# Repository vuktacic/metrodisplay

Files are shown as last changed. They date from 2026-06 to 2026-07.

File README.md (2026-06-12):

# MD
## Description
MD (metrodisplay) is a big LED matrix assembly with game controls to play pong and tetris (in progress). It's built with four outdoor (very bright) P5 64x32 panels, a custom pcb with an esp32, a cnc'd wooden frame, and power distribution from mains AC. The total cost of the project is under $90 USD.

I was originally making a small project with a single LED panel to display subway times for the Vancouver Skytrain (hence the name), but I realized that while that was great for a static bedroom display, something much more exciting and interactive like this would be much more fun to showcase at Opensauce!

## TODO List
- [x] Pong game
- [ ] Tetris game (in progress)
- [ ] Concept art
- [ ] CNC designs
- [ ] CNC toolpathing
- [ ] CNCing
- [ ] Frame building
- [ ] Electronics Setup
- [ ] Final tests
- [ ] Dismantling
- [ ] Present at Opensauce!

## Structure
- [./cad](./cad): STEP & F3D
- [./pcb](./pcb): PCB Files.
- [./mdcore](./mdcore): Firmware
- [./bom.csv](./bom.csv): Bill of Materials
- [./JOURNAL.md](./JOURNAL.md): Journal

View the PCB on KiCanvas:  


## CAD
### Frame
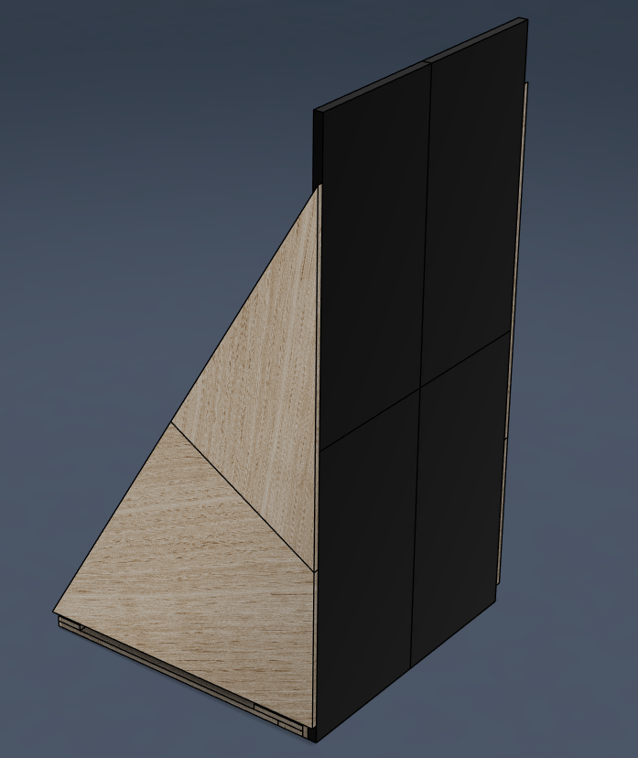
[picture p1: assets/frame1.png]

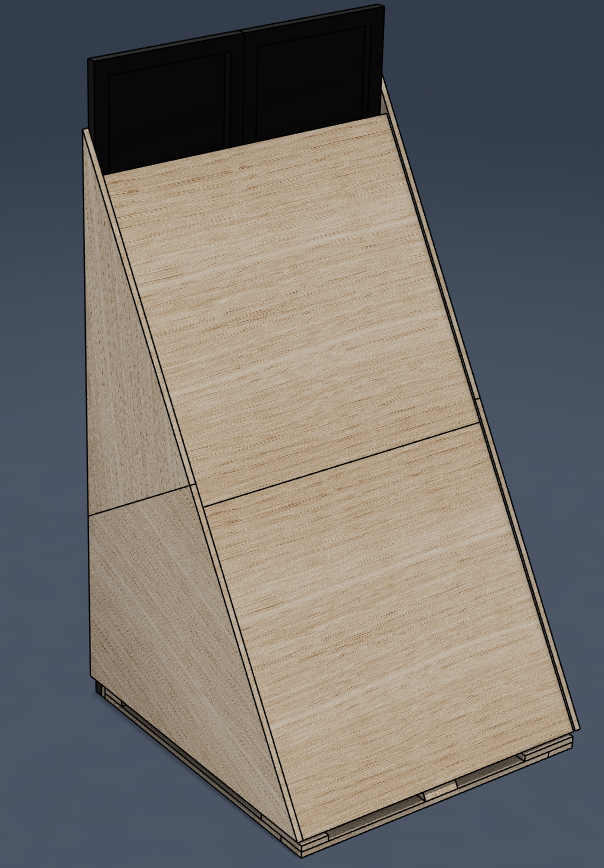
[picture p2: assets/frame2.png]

Frame designed to be disassembled to fit in standard carry-on luggage.

### Controllers
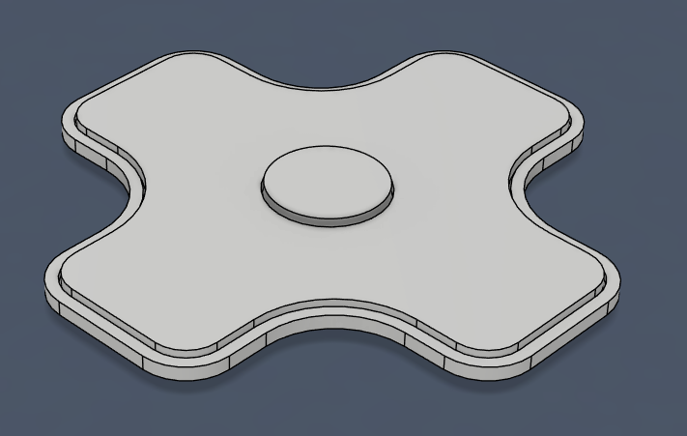
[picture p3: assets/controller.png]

Controllers are 22cm wide

## Electronics
### PCB
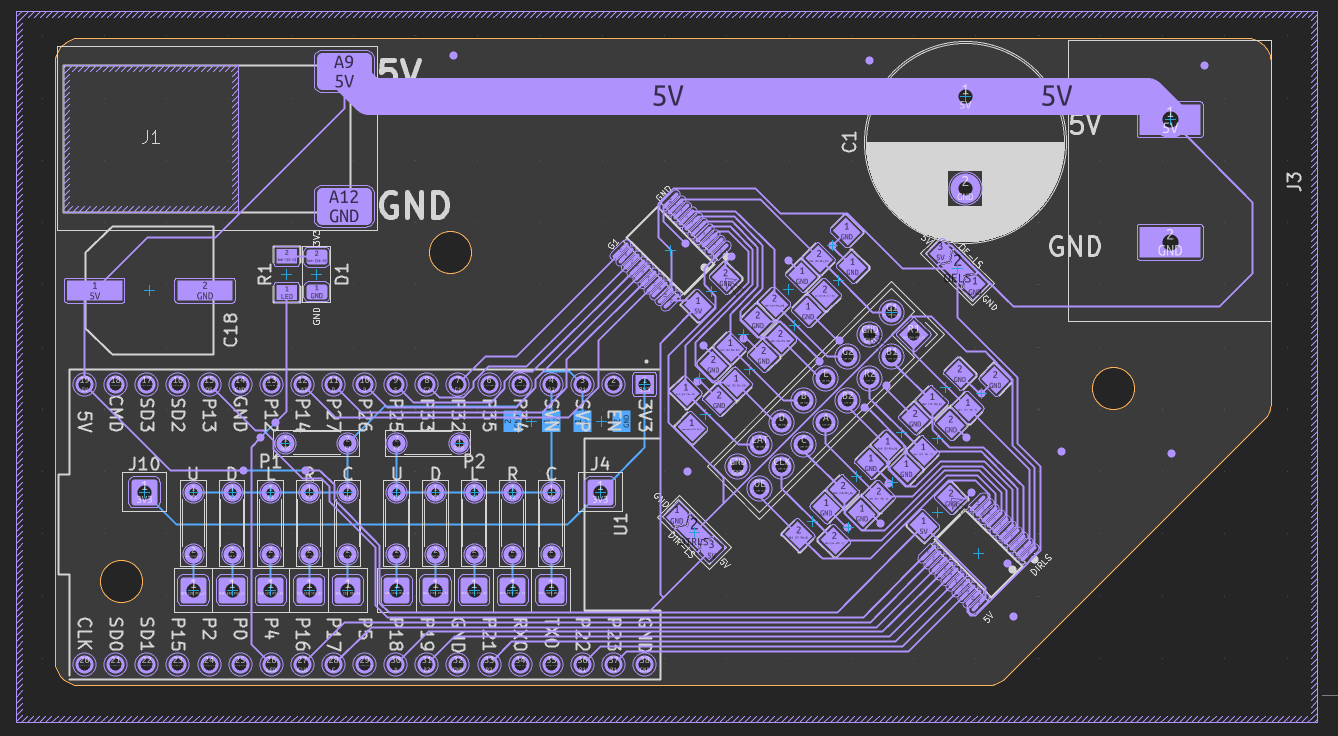
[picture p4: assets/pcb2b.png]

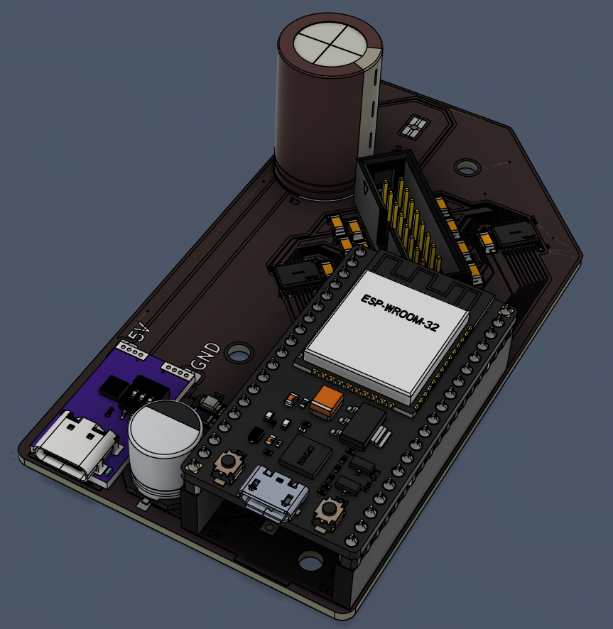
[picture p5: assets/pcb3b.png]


### Schematic
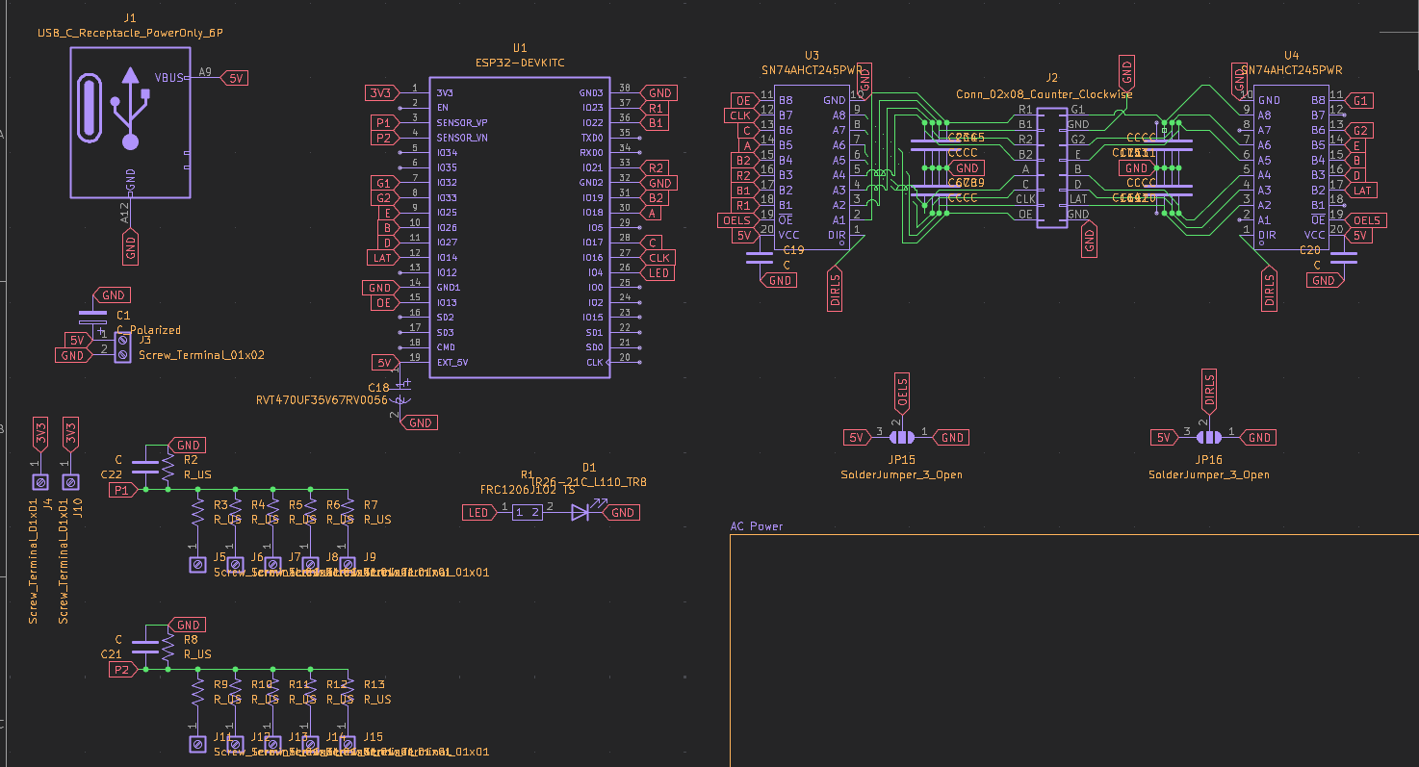
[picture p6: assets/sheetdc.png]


### Power Distribution
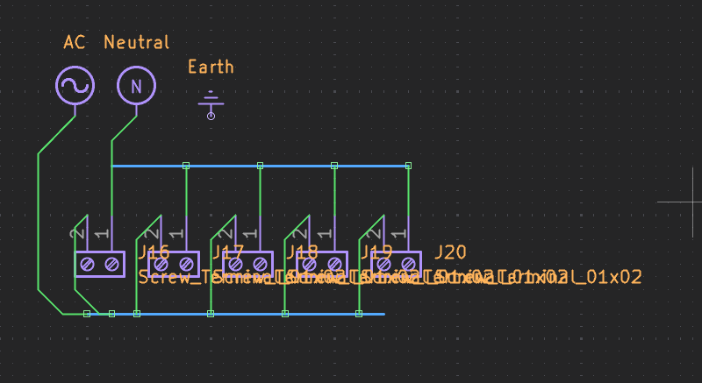
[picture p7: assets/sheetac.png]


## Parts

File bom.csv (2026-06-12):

Item | Qty | Price (CAD) | Link | Note
Outdoor P5 64x32 LED Panel (320mmx160mm) | 4 | $108.76 | https://www.aliexpress.com/item/1005003654005236.html | 1/8 scan
2x4 wood | 1 | $0.00 | n/a
1/8 in plywood 3'x6' | 1 | $0.00 | n/a
2.54 MM Pitch DC3 2x8 16P Socket Box Header | 10 | $2.25 | https://www.aliexpress.com/item/1005004252439201.html | PCB connector
SN74AHCT245PWR TSSOP20 Level Shifter 3V3 to 5V | 10 | $4.19 | https://www.aliexpress.com/item/1005006837883056.html | Translator for LED Panel
ESP32 Devkit | 1 | $0.00 | n/a
1206 Blue LED | 1 | $0.80 | https://leeselectronic.com/en/product/55614-led-1206-smd-blue.html
100nF 1206 Ceramic Capacitor | 19 | $0.00 | n/a
470uF 25V Electrolytic Capacitor | 1 | $0.00 | n/a
1kΩ 1206 Resistor | 1 | $0.00 | n/a
10kΩ THT Resistor | 4 | $0.00 | n/a | Pulldown Resistor & Resistor Ladder
1kΩ THT Resistor | 2 | $0.00 | n/a | Resistor Ladder
2.2kΩ THT Resistor | 2 | $0.00 | n/a | Resistor Ladder
4.7kΩ THT Resistor | 2 | $0.00 | n/a | Resistor Ladder
22kΩ THT Resistor | 2 | $0.00 | n/a | Resistor Ladder
6mmx6mm Push Button | 10 | $0.00 | n/a
5-way WAGO Splitter | 2 | $0.00 | n/a | Power Distribution
AC Power Cable | 1 | $6.99 | https://www.aliexpress.com/item/1005001405584434.html | Power
JLCPCB | 5 | $4.89 | https://jlcpcb.com/
**TOTAL (CAD)** |  | $127.78
**TOTAL (USD)** |  | $91.45

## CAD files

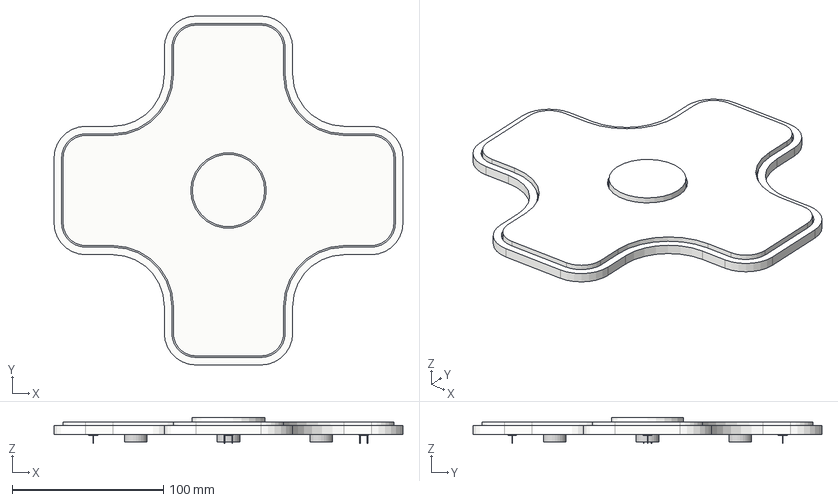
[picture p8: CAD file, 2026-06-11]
cad/Controller.step
231.0 x 231.0 x 17.5 mm
part_object_id_9 x 5
part_object_id_10 x 5
part_object_id_11 x 5
part_object_id_12 x 5
part_object_id_13 x 5
part_object_id_14 x 5
part_object_id_15 x 5
part_object_id_16 x 5

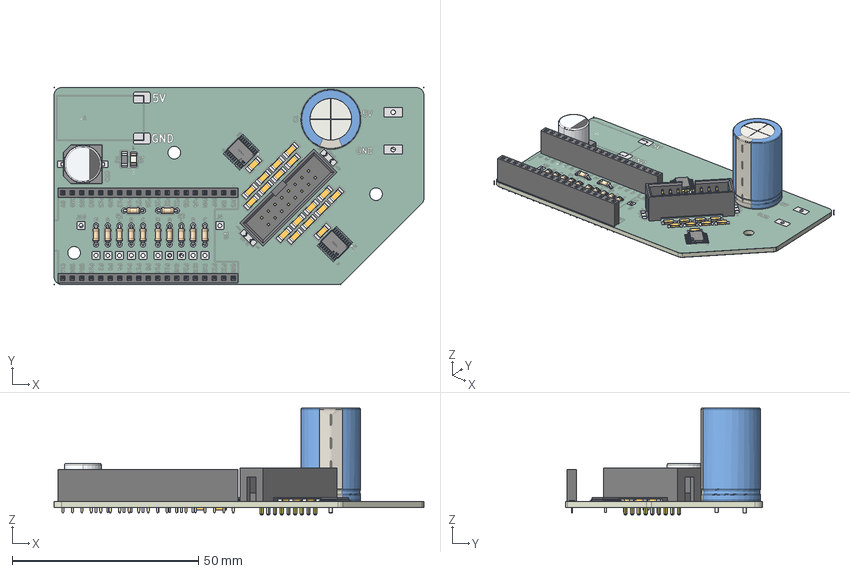
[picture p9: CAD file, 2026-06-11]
pcb/pcb.step
99.3 x 52.9 x 28.6 mm
C1206_L3.2-W1.6-H1.3 x 20
R_Axial_DIN0204_L3.6mm_D1.6mm_P5.08mm_Horizontal x 12
DS1013-16S (IDC-16MS CONNFLY)
LED_1206_3216Metric
TSSOP-20_L6.5-W4.4-H1.0-LS6.4-P0.65 x 2
R1206_L3.2-W1.6-H0.6
PinSocket_1x19_P2.54mm_Vertical x 2
CP_Radial_D16.0mm_P7.50mm
CAP-SMD_BD10.0-L10.3-W10.3-H10.2
metrodisplay_copper
metrodisplay_pad
metrodisplay_via
metrodisplay_silkscreen x 2
metrodisplay_soldermask x 2
metrodisplay_PCB_1
metrodisplay_PCB_2
metrodisplay_PCB_3
metrodisplay_PCB_4
metrodisplay_PCB_5
metrodisplay_PCB_6

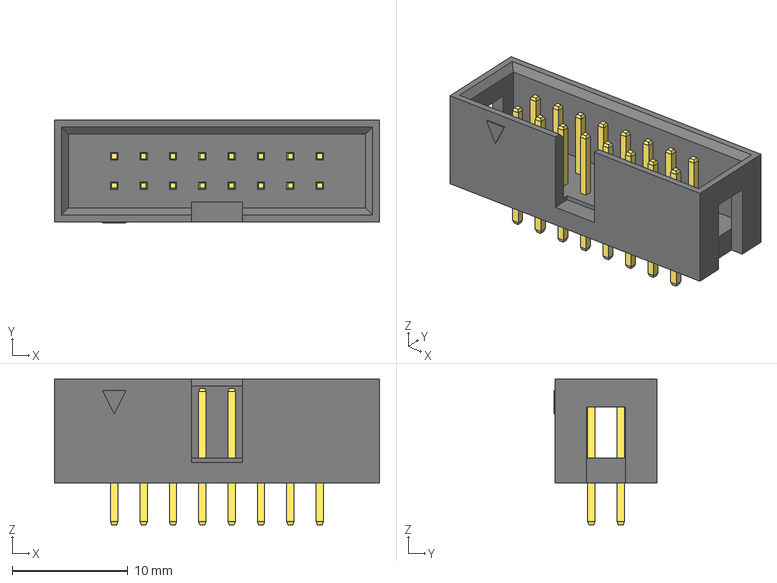
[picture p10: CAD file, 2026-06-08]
cad/DS1013-16S (IDC-16MS CONNFLY).stp
28.1 x 8.90 x 12.6 mm

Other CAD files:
cad/Controller.f3z

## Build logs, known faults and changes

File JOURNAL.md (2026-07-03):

# MD Journal

## June 5th, 2026

Started working on my project. This has been on my mind for quite a while: an led matrix board that displays subway timetables.

I've seen quite a few projects of this online, but they all use low resolution led matrices, or use them from overpriced suppliers (sorry adafruit).

First thing I did was find the led matrix I wanted to use. I found a 128x64 led matrix on aliexpress for ~$35CAD. Sounds expensive, but a 64x32 from adafruit is twice as expensive for 1/4th the pixels, so I think it's a pretty sweet deal.

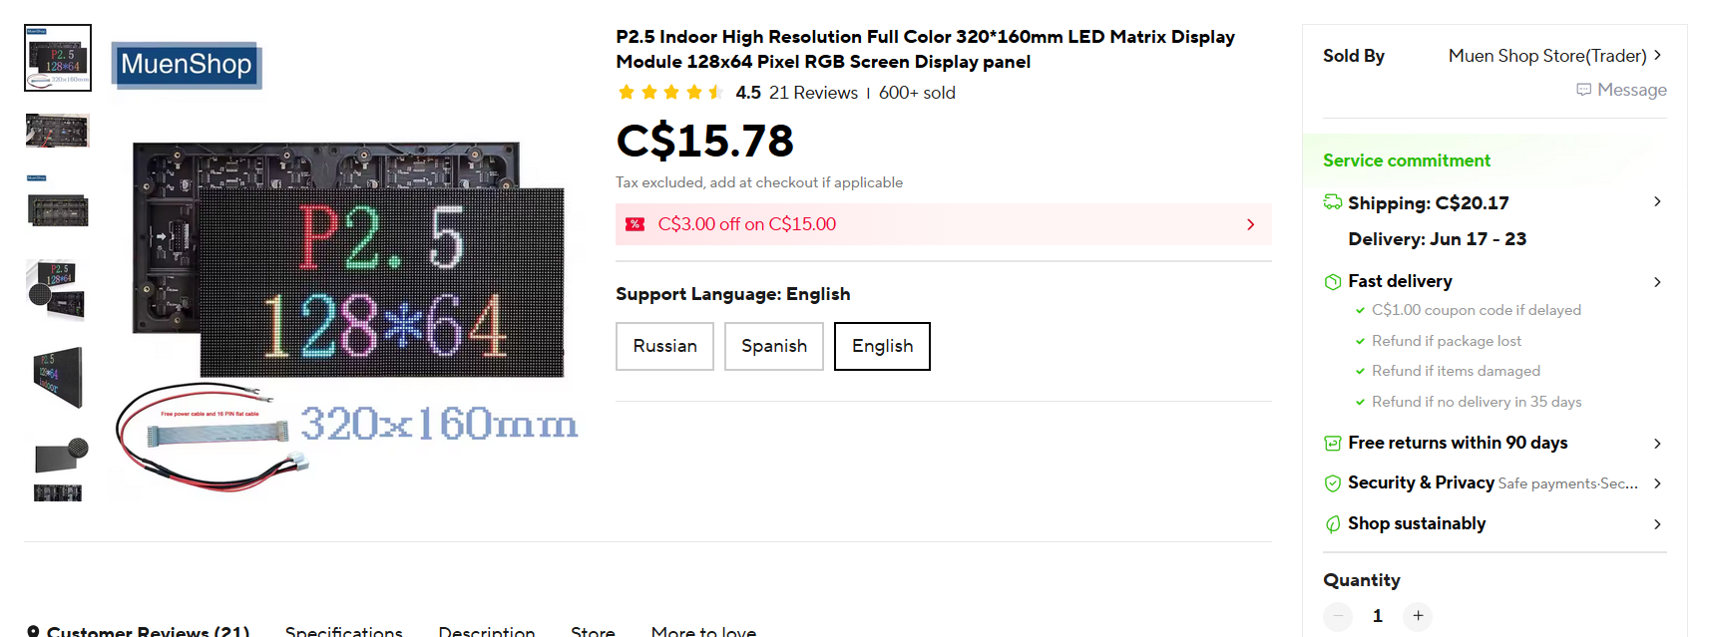
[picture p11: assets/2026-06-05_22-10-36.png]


I then built a schematic centered around my esp32 devboard to run this display.

The matrix uses a 2x8 IDC pinout, presumed to be 2.54mm pitch. I added a button for control, an led for status, level shifters for the data lines (to upgrade the 3.3V logic from the esp32 to 5V for the display), and lots and lots of decoupling capacitors (including a BEEFY 2200uF cap for the display).

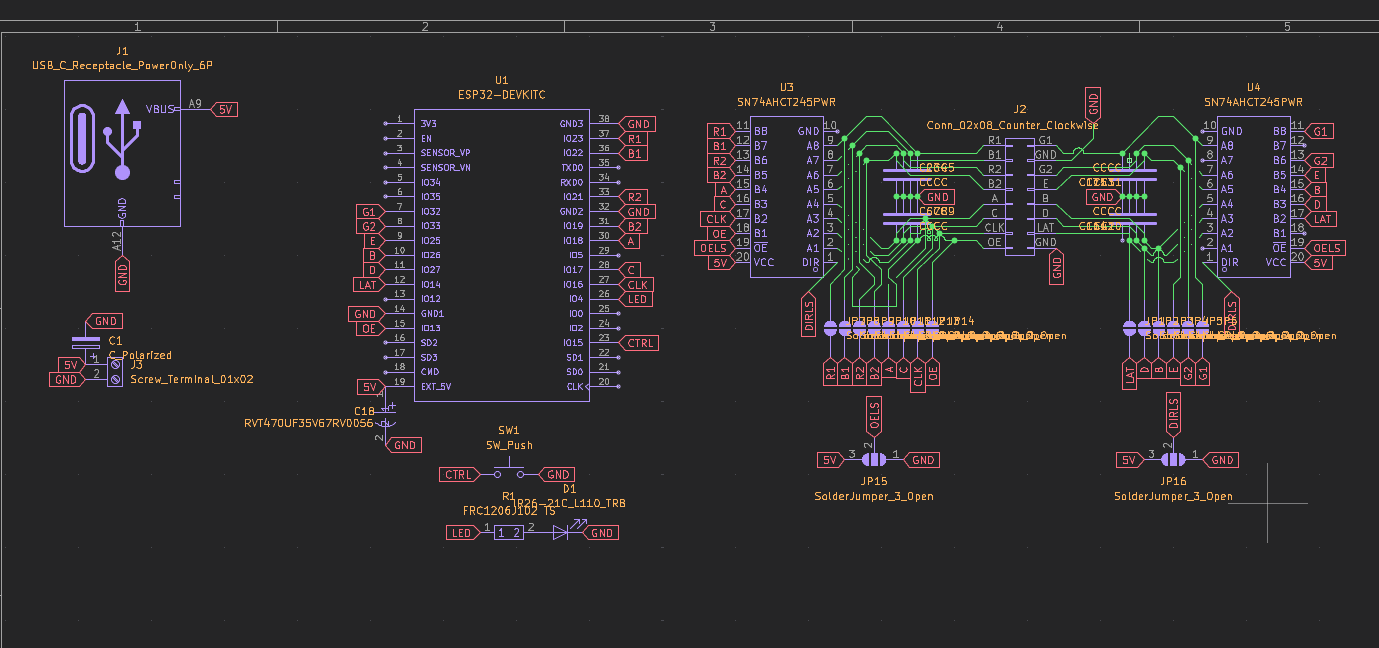
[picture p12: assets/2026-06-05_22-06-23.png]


As you can see the level shifting schematic is a bit of a mess because of how many lines there are. I added solder jumpers just in case I'm unable to use the level shifters, and the display still works with 3.3V logic.

About that capacitor: I found several boxes full of these in my school's shops (I'm talking maybe 100+ of these things). I don't think they've ever been used for something other than students blowing them up for fun, so I'm pretty excited to have a practical usecase for one of them.

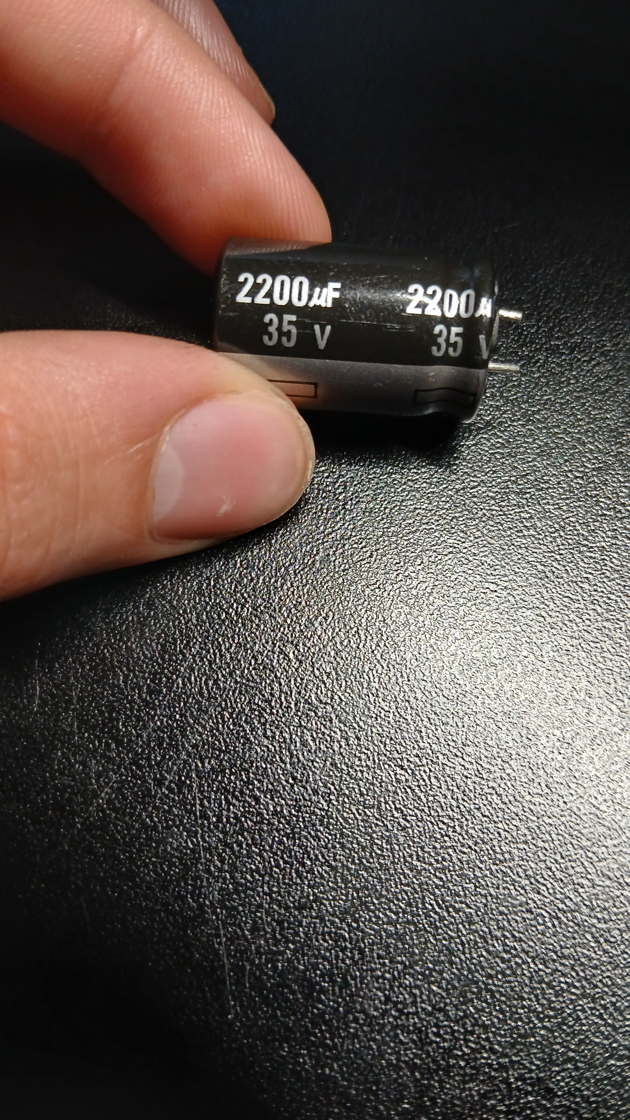
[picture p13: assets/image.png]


I then assigned footprints and brought everything into the editor. (No errors!). I set a 100mmx100mm box (JLC price limit), and started arranging the components. I wasn't worried about precise alignments, as the goal was just to see if everything could fit nicely.

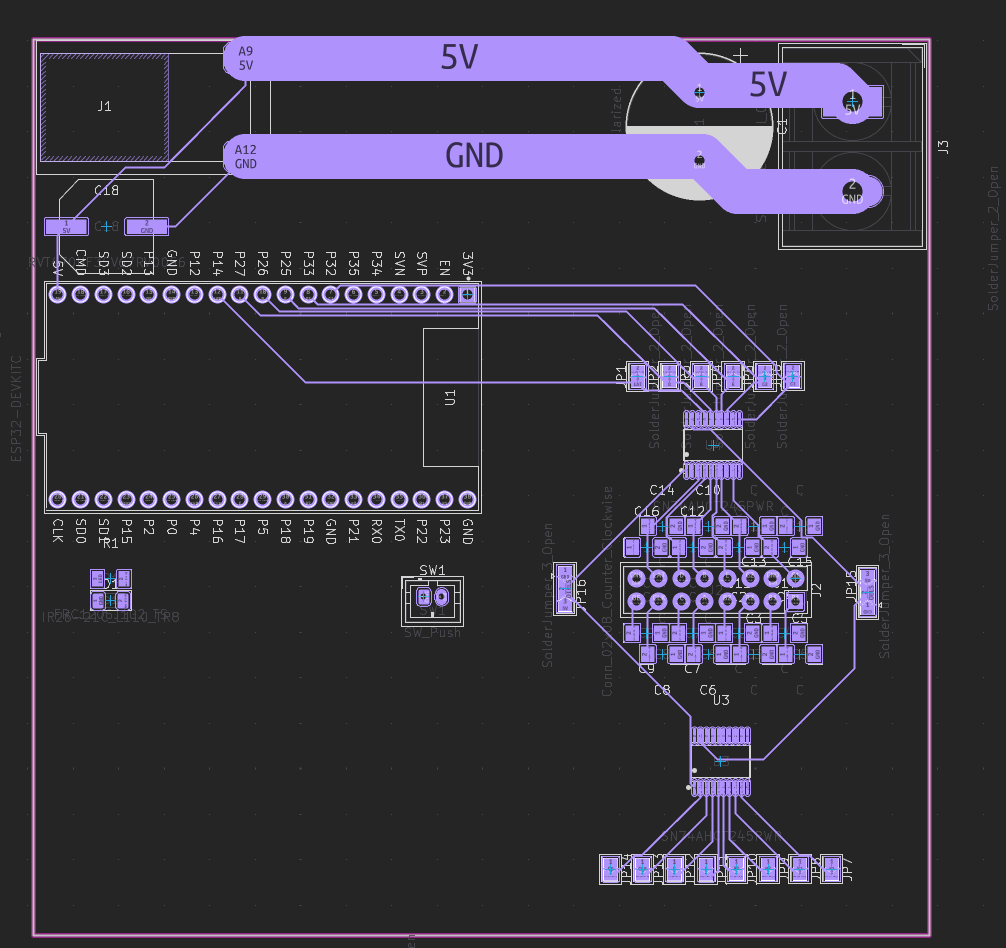
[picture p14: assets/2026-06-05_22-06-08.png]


Well, there is quite a lot of room there. I will still need to add vias for some of the solder jumpers though.

I also put down 5mm wide traces for the led 5v/gnd rails. Overkill? Yeah. But I'm not taking any chances when this matrix flicks on and pulls a billion amps.

In the following days I'll put down the actual aligned placements of all of these components, and then start routing. After that, I'll design the case for the pcb and display, and then write the firmware for it (I'm considering a webserver).

Time today: 6.0 hours  
**Time total: 6.0 hours**  
_(I'm probably going to include lapse links from now on.)_

## June 6th, 2026
Routing done!

I made a couple changes to my schematic:
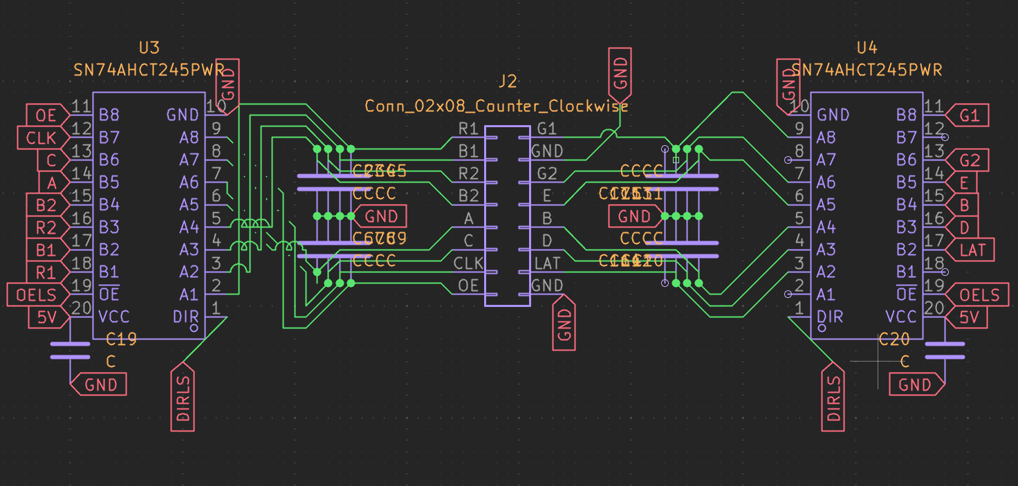
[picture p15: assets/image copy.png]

I had to swap the connections of the left level shifter to make the routing better. However at first I swapped the right level shifter, and it took me a good few minutes to realize I had to swap the left one.

I also added decoupling capacitors for the level shifters themselves.
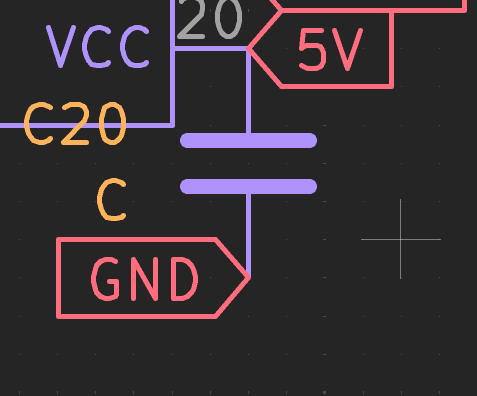
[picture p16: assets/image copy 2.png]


As for other changes, I removed the unholy amount of solder bridges. They probably won't be used and take up a LOT of space.

I then routed the entire PCB in one sitting.
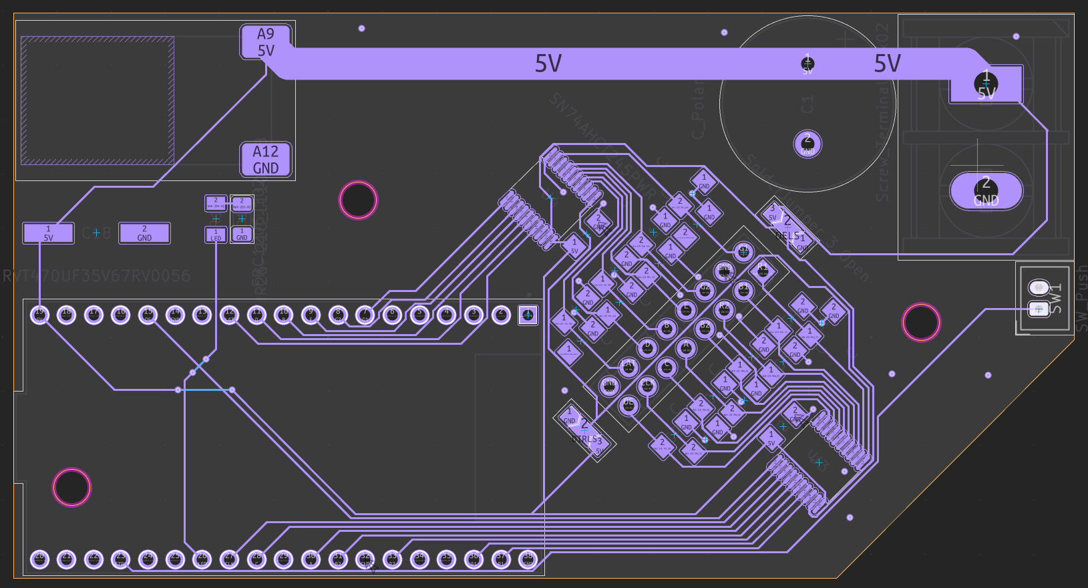
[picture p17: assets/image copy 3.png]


I kicked down the 5V rail from 5mm wide to 3mm wide. At that width it would still be at a manageable temperature even with a lot of amps flowing through it.

I rotated the whole HUB75 connector, level shifters, and decoupling capacitors 45 degrees. The official reason was to package it on a smaller pcb. The real reason is that it has more aura.

Overall the routing was pretty nice. I was able to route all the capacitors to the level shifters in a nice consistent pattern. Likewise for the level shifters to the ESP32. I only had to do vias + back routing for the led and the HUB75 5V rail (and even that was <1mm long each).

I then added some stiching vias so that all of the ground pads and pours could be connected together.

I then ran into a hiccup: there was no clearance for the IDC connector. The standard HUB75 connector uses a 2.54mm pitch 2x8 IDC connector. However, those are ~9mm wide. I only had 7.5mm of space. I had to select each half of the connector and move the capacitors and level shifters a millimeter vertically and a millimeter horizontally to make room for it. It went smoother than expected, but it was still a pain in the ass to cleanup missed tracks and move vias into position.

However, it's done! The silkscreen is a mess right now, but I can whip it into shape. I am also planning on making a logo for this in figma (hopefully a little less shitty than my vdar logo).

Time today: 3.5 hours  
**Time total: 9.5 hours**  
_(Btw lapse is kind of shitting the bed for me rn so I wasn't able to get it to work.)_

## June 7th, 2026
Fixed up the silkscreen for the board!

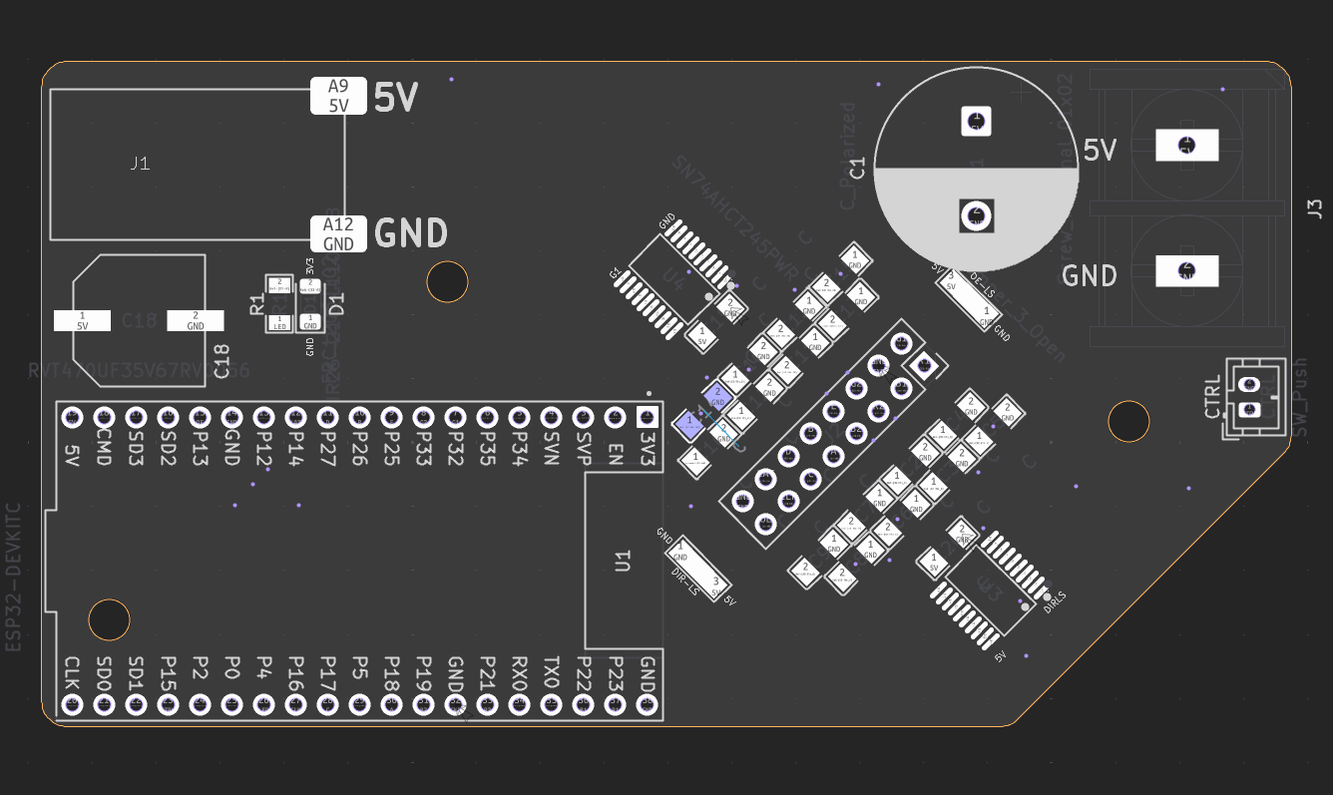
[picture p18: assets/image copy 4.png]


I added labels for 5V and ground everywhere. I also made sure to label the solder bridge sides because that was a bit of the pain in the ass last time.

I also created an edgecuts sketch in fusion 360 with rounded corners and correct mounting hole placements to be imported into kicad.

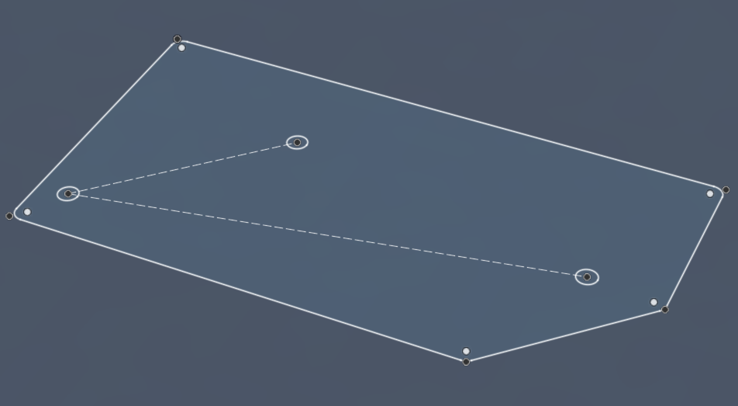
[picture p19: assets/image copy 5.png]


An issue I ran into was sourcing correct 3d models for the components. I scaled the beefy capacitor up to match the height of the real life one. However, I had do about a half hour of digging on grabcad and forums to find a valid IDC 2x8 2.54mm pitch connector.

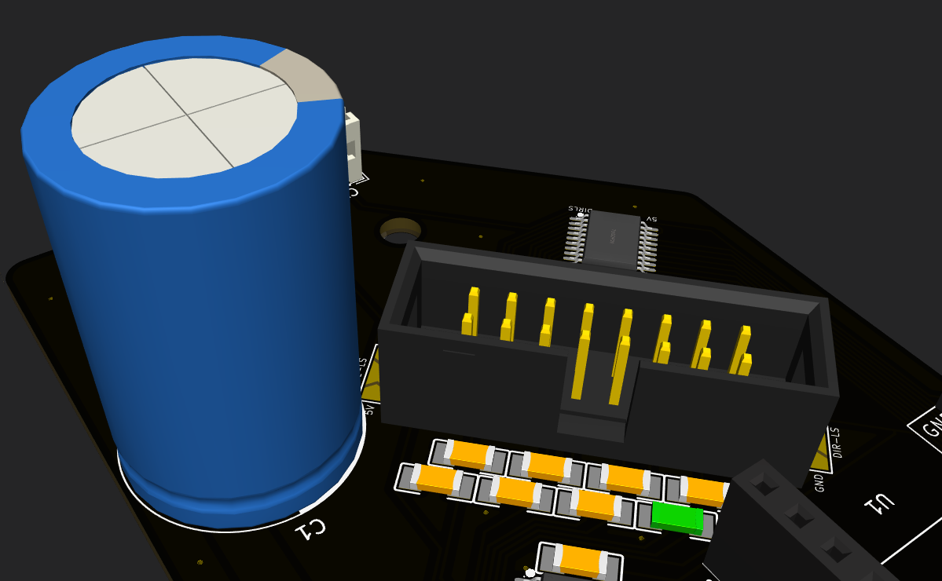
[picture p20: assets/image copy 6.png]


I then had some fun in figma to create graphics for the backside of the board.

I pulled my logo, the maple leaf, the hackclub logo, and vectorized the OUTPOST png on the website.

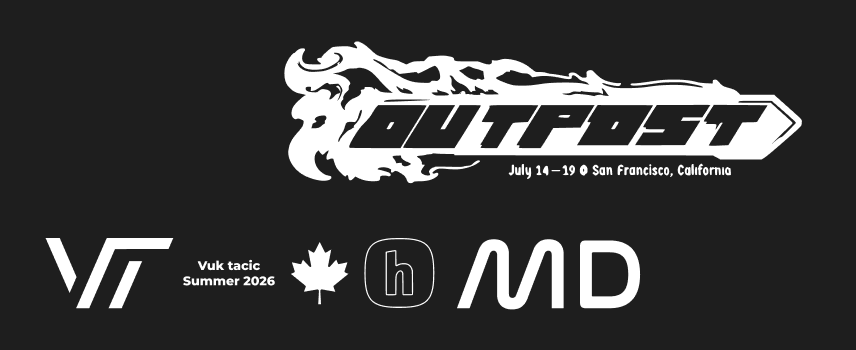
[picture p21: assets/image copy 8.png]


I placed these on the back of the board.

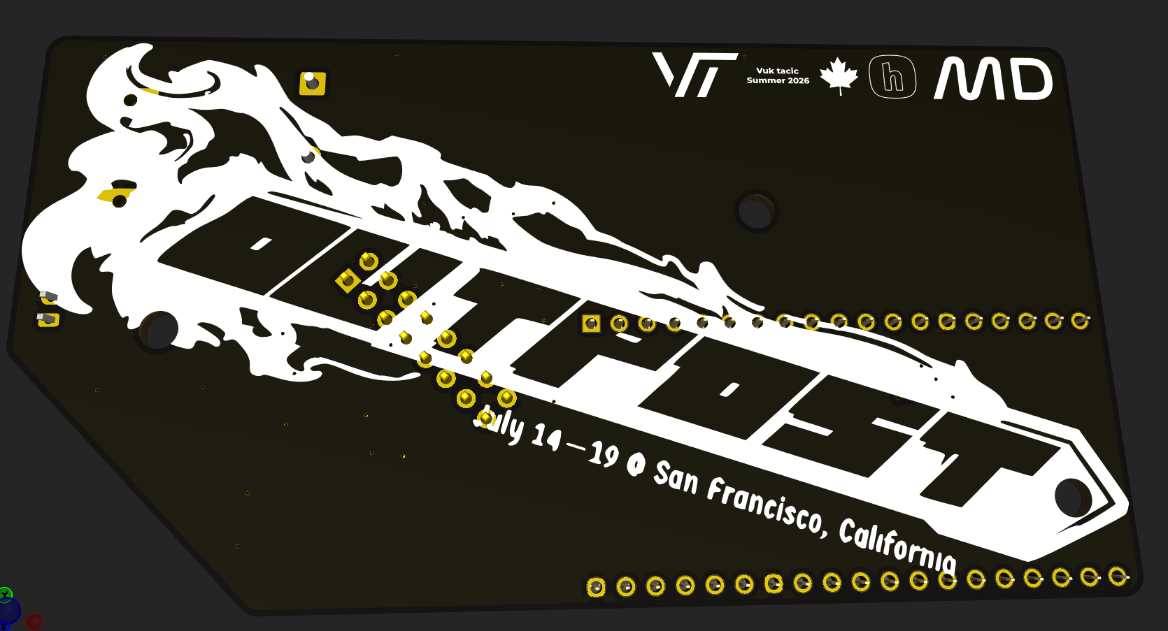
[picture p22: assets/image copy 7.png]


It took a bit of effort to find something that worked. I originally had them all clustered up, but that left a ton of empty space (and that wasn't the best on my previous board). I decided to split up the the outpost logo away from the rest of the logos, and then scaled it all the way up so that it would stretch across the entire board. It looks really nice now.

I went into fusion to populate the usb-c decoy board and the ESP32.

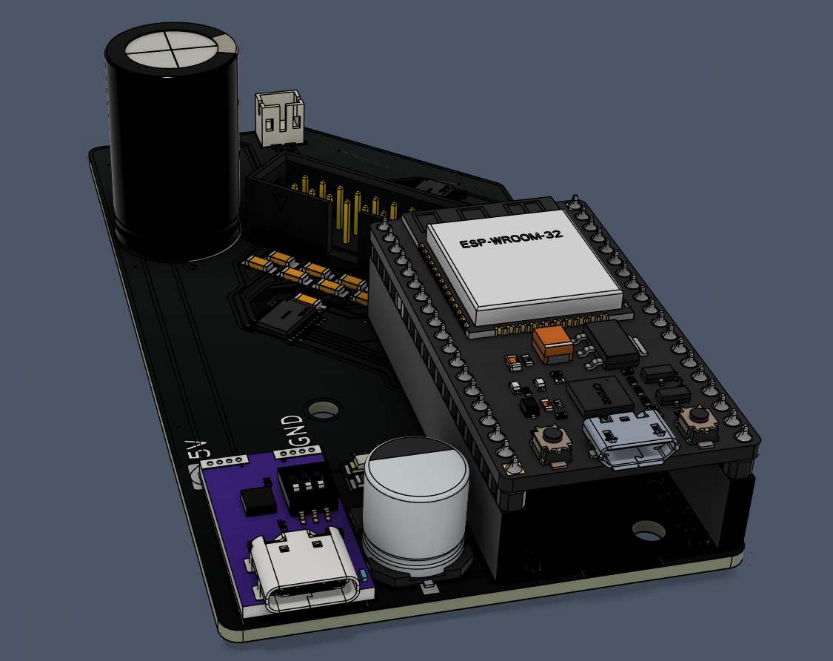
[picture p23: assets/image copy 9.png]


With that, the PCB design is done! I'll need to create an enclosure/box for the led-matrix and the board, and then write the code to display subway times and potentially a few animations.

Time today: 4.0 hours  
**Time total: 13.5 hours**  

## June 9th, 2026
CADed a shitty enclosure for the board and display.

I started with the top slanted part:
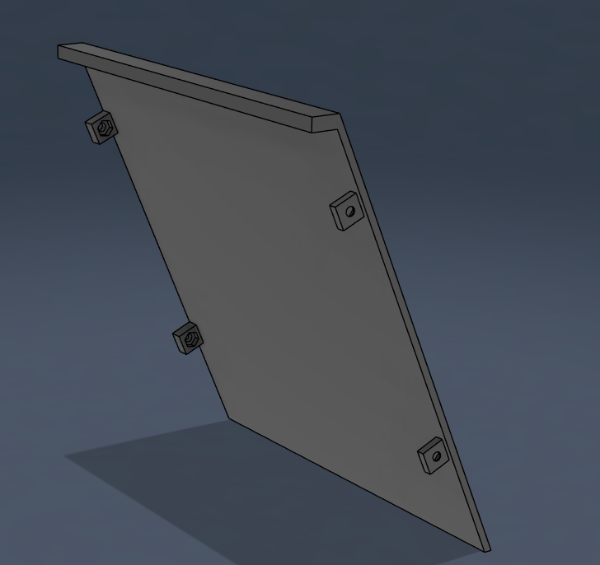
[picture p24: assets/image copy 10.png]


I had to slant it for:
a) stability when lying horizontally and vertically
b) to fit the massive ass capacitor on the circuit board

I then made a side piece with an opening for usb-c power input:
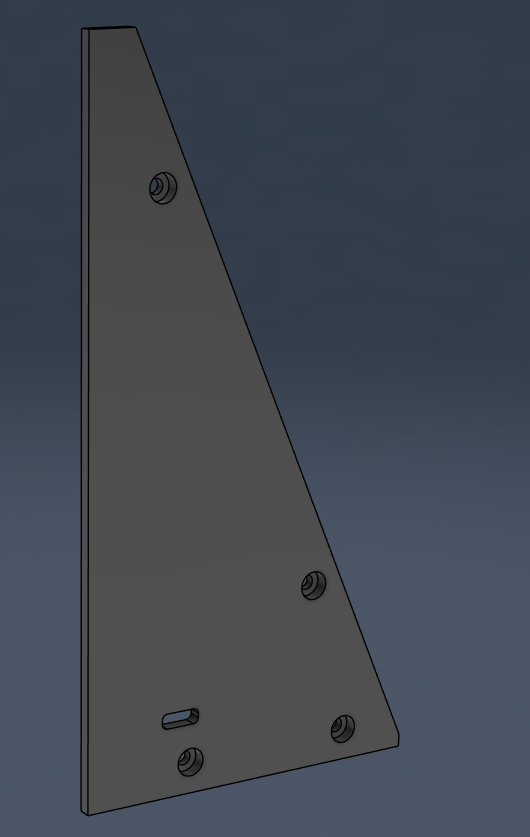
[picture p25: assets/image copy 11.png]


And then a bottom cover with alignment tabs and circuit board mounting pillars (this is where the drawing of the pcb edge cuts was useful!):
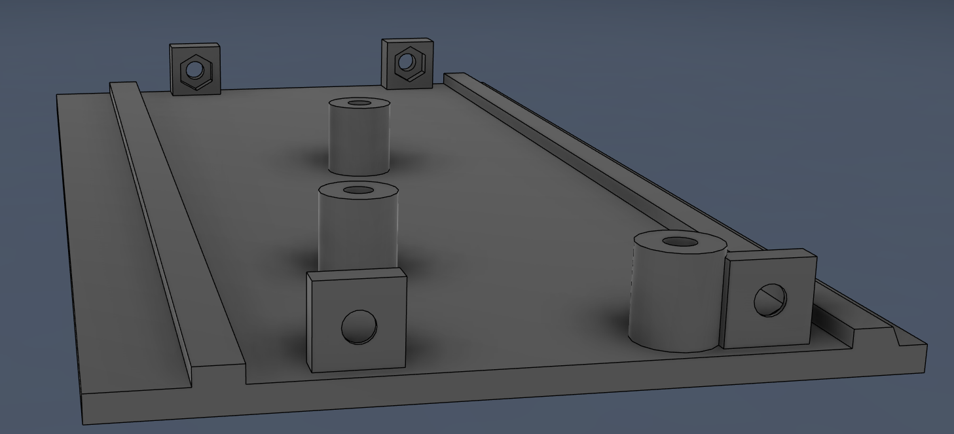
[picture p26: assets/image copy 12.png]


I then had to put down hex holes for my m3 nuts:
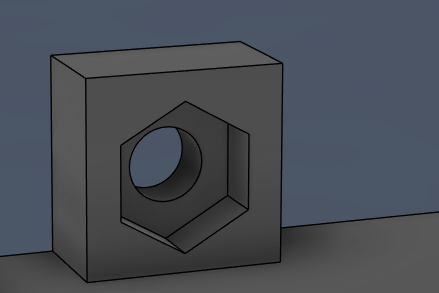
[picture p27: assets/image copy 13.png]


I've decided that I will actually make them 0 tolerance like vdar! Originally I was planning on putting +0.2mm for slip fit, but I realized me accidentally leaving no tolerance was a blessing in disguise. If I leave it that way, then I can use my pinecil to heatpress the hex nuts in place. This means less fumbling around with keeping them in place during assembly!

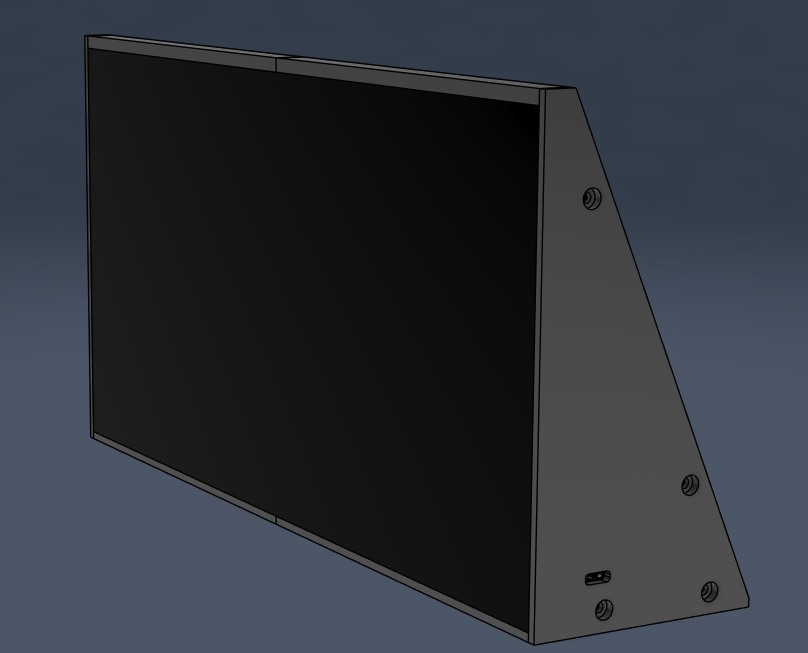
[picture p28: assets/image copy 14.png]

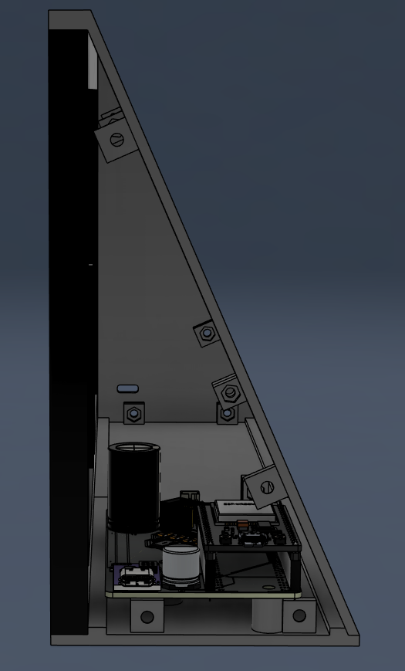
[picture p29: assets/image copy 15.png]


This was a speedcad. I want to get started on the code tomorrow, and then return to the cad to clean it up and refine it. (I want to add a portait stand and branding.)

Other than that, I'll also need to make some pcbs for the controllers (huh?)

If it wasn't said before, I'm pivoting! A metrodisplay is a great static piece for my bedroom, but it's not exactly that flashy at opensauce. I'm adding two to four controllers so that people can play tetris or pong on the display!

Time today: 4.0 hours  
**Time total: 17.5 hours**  

## June 10th, 2026
So, controllers...
I am running out of pins on my esp32. I did a little bit of research and discovered something called a resistor ladder. This was basically the exact thing I was envisioning in my head (having each button output a different voltage, and using ADC to read it).

I went into kicad and whipped in the schematic for the controllers.
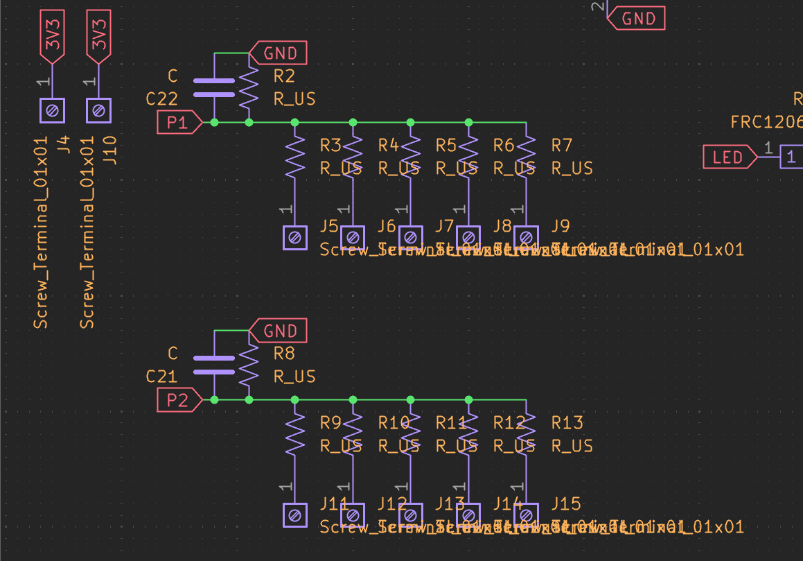
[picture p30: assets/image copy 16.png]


(I know, I know, the labels are covering each other.)

I then imported them into my pcb. I REALLY wanted to avoid having to change the edge cuts, as that could completely throw off whether it would be able to fit into the enclosure. However, I realized that because these were simple low profile THT resistors, I could actually just put them underneath my esp32!

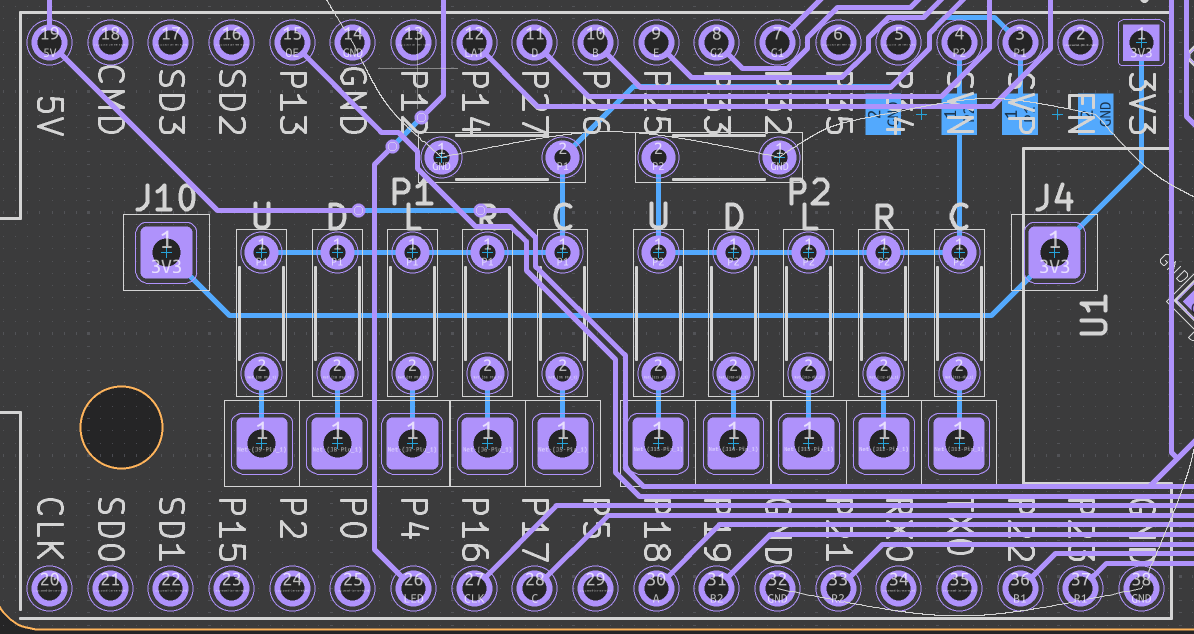
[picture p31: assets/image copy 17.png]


This was super convenient, as the pcb had an identical footprint, and I didn't have to change anything at all.

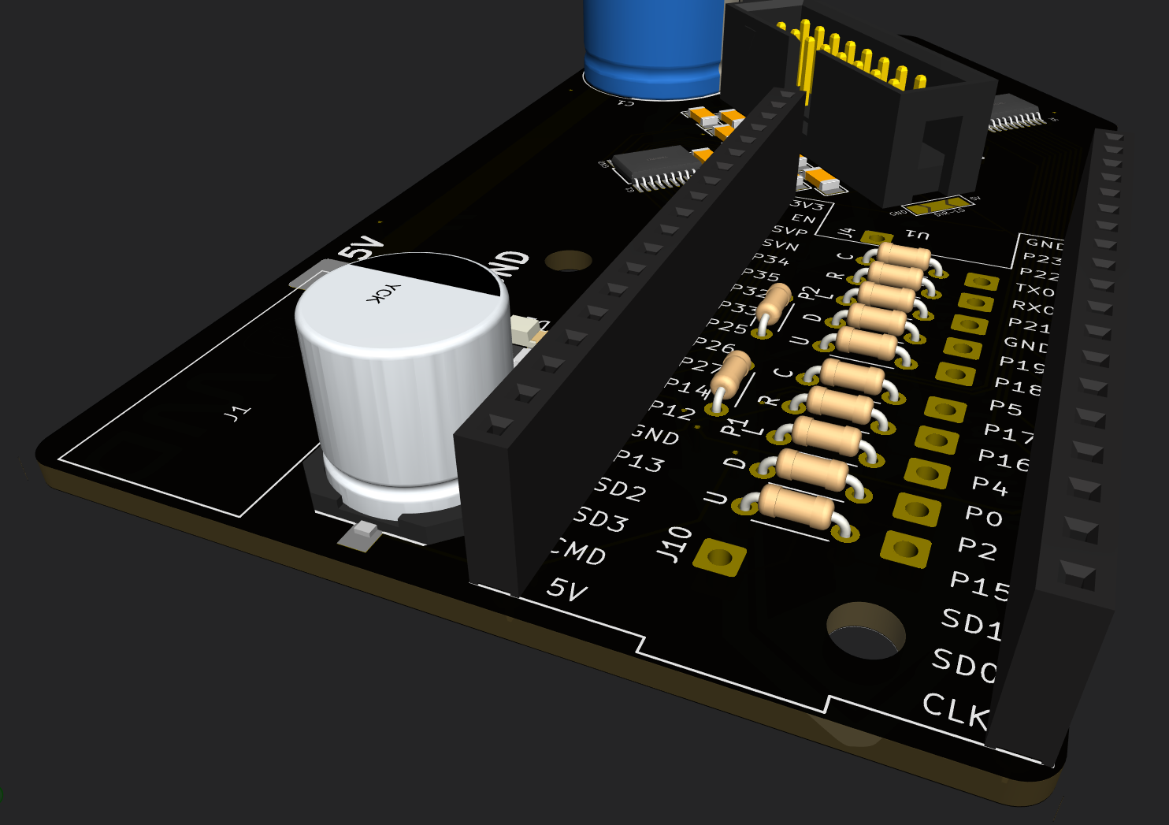
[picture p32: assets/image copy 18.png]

Also: the empty pads are for me to solder wires onto.

I then started working on something new: the BIG display. four panels stacked together to make a 64cm x 32cm display.
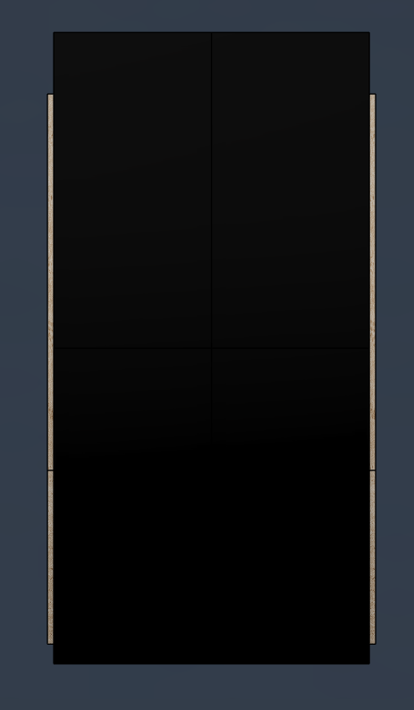
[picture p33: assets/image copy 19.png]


I then started building an enclosure/stand for it. This was tricky, because I had to make sure that all the individual pieces would be able to fit in my carry-on luggage. I would also be cncing this on our schools router, so I designed it around 1/8" plywood.

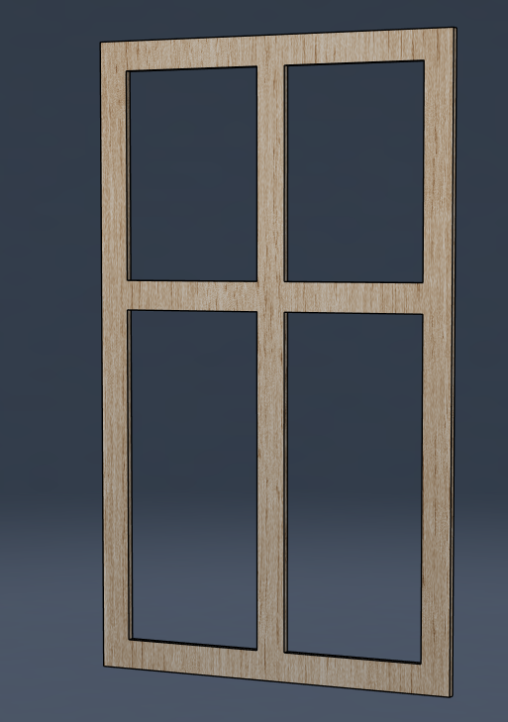
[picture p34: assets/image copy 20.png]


This was the first piece, it barely fits in my luggage and honestly I might need to cut it down, but it's to hold all the panels together on one bhoard.

I then designed a bottom stand.

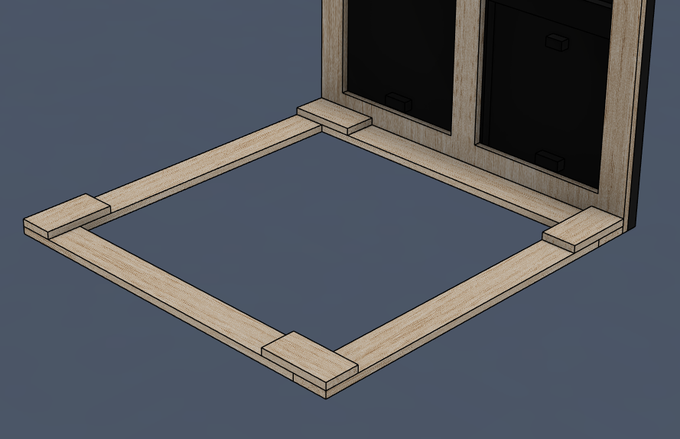
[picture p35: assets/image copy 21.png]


And a 2x4 to hold it up.

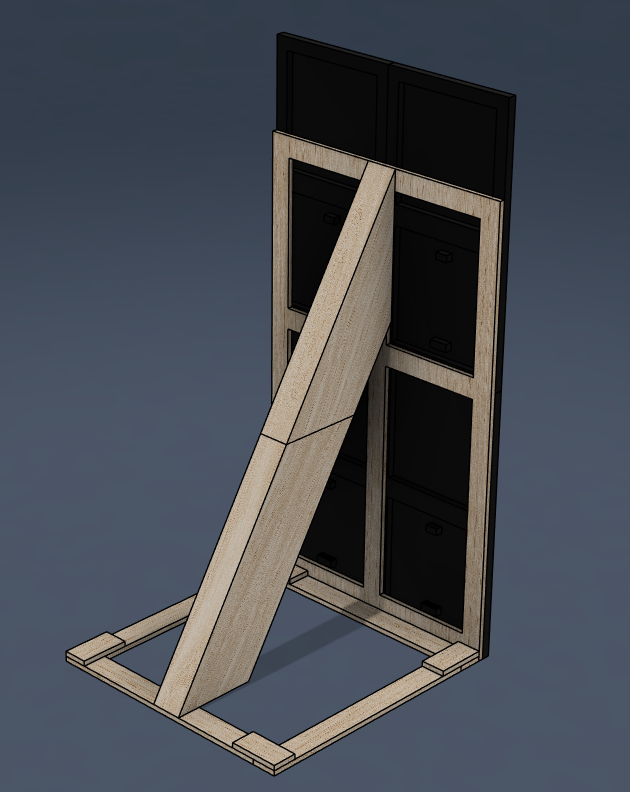
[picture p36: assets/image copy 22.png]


Back panels & side panels. (I had to cut these in half to make it fit in my luggage).

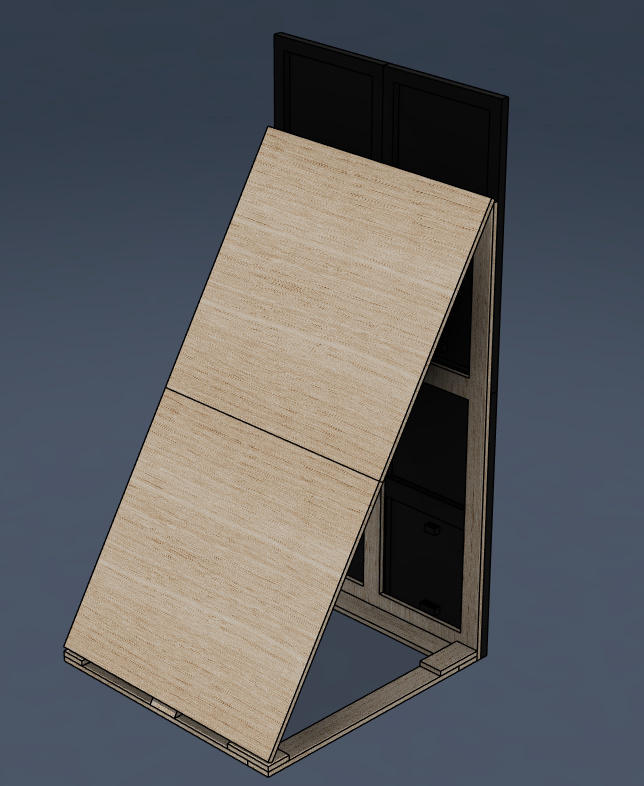
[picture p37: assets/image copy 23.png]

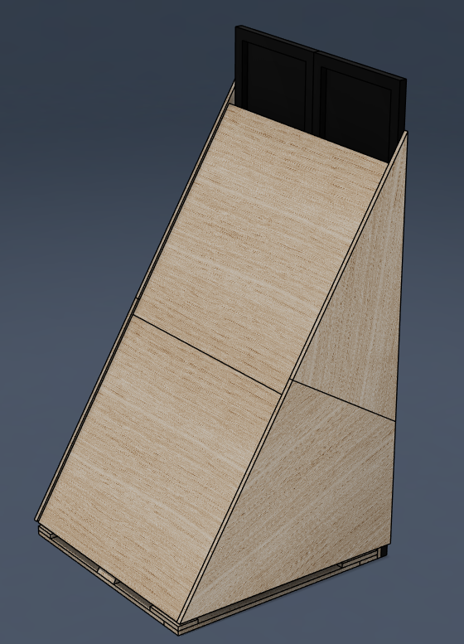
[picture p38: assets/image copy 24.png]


TSA is going to have a field day with this. Not a lot of people bring plywood and a 2x4 in their carry-on luggage.

Anyway, these panels are actually really nice. They provide a lot of flat space for cnced designs/branding. I can also paint them with some kind of design!

That's the CAD.

As for programming, I spent 3 hours making a pong game, but I don't have to journal that ;)

Time today: 3.0 hours  
**Time total: 20.5 hours**  

## June 11th, 2026
Spent today getting the repo together for submission. I create the [bill of materials](./bom.csv) and populated the [README](./README.md) with info and a bunch of screenshots of the project.

Not really much else to say lol.

Time today: 1.0 hours  
**Time total: 21.5 hours**  

## June 12th, 2026
I started collecting my wood for the display
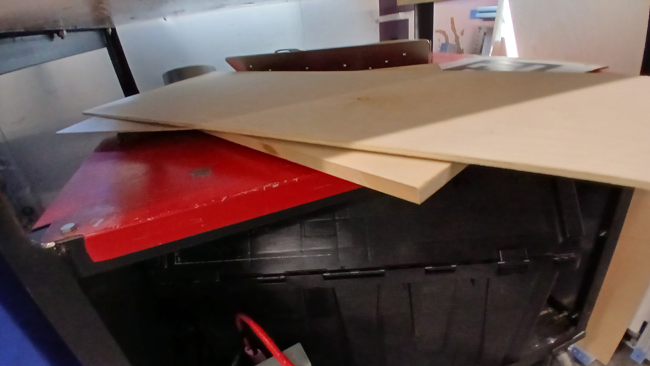
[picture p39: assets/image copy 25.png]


Thin plywood for the panels, and thick 1/2" mdf for the stand.

I realized that there wasn't really a need for the cnc router. I can instead do it on our cnc laser cutter! This will allow for way more detailed designs, as well as shading in the form of etching. I also don't have to worry about keeping the wood steady during cuts.

I drew the stock bounds in fusion and fit all my pieces into it.
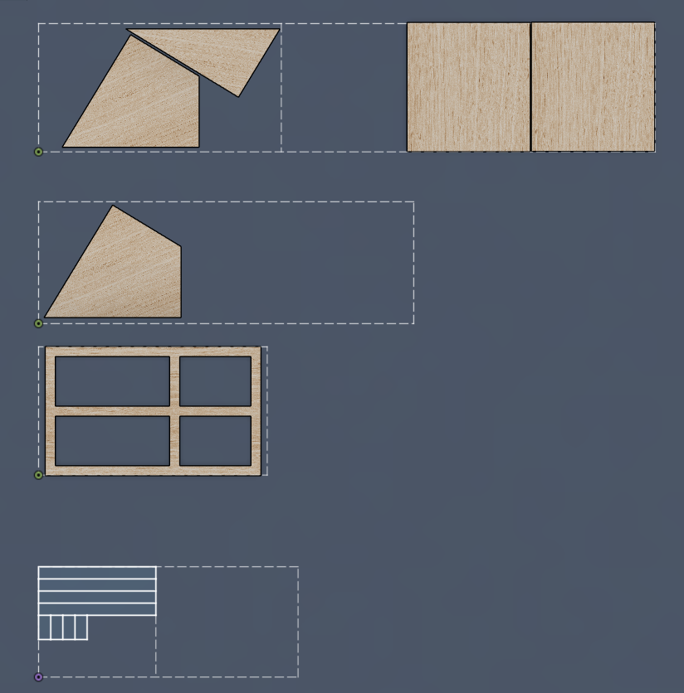
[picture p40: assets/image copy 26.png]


Over the weekend I'll work on the artwork. Come Monday, they'll be cut out!

Time today: 2.0 hours  
**Time total: 23.5 hours**

## June 15th, 2026

Cut out the wood today!



One of my friends may or may not have accidentally taken my plywood and used it for his own project, so I had to find a bunch of pieces that would fit.

It did take a lot of effort, But I eventually found a long piece. I had to snap it into chunks to get it to fit in the laser cutter, which did require quite a bit of strength.

As for the moutning panel, it's slightly messed up (you can see the tiny sliver in the photo). However, it's going to be hidden behind the display, and testing the strength of the sliver, I believe it will be fine in holding up all the LED panels.

In other news though, all of my parts have been shipped and are currently at the airport (in Shenzen, I presume) waiting to be flown across the pacific!

Time today: 1.0 hours  
**Time total: 24.5 hours**  

## June 27th, 2026

All the parts arrived! The pcbs look dressed to kill in red soldermask, and the led matrices are nice and big.





I then spent 3 hour soldering the pcbs in something best described as a learning experience. I soldered all the caps on first, and then tried soldering the tiny ass level shifters. I ended up ripping the pads off the pcb. I then took a replacement pcb (glad jlc ships 5 moq), and got the level shifters on eventually. It was terrible. I spent so long getting solder bridges off the pads. I still don't really know how to properly do it. I just rub my iron against the pads and then hope and pray that I'm able to get the bridges off with random motions of my soldering iron.





I then soldered all the capacitors on and header pins. However when it came to the big 470uF capacitor for the esp32 VIN, I just straight ripped a pad off. Not fun. But i've decided it isn't necessary, and that I'll just tie the usb-c power to the 5v rail directly with a jumper.



Overall, not fun.

[Lapse link](https://lapse.hackclub.com/timelapse/s83o4plg0MXk)

Time today: 3.25 hours  
**Time total: 27.75 hours**  

## July 2nd, 2026
I soldered up the box header and the resistors on the board today.

I decided to use a resistor ladder. I forgot to nab some from the school shop before leaving so I had to make do with what was in my arduino kit: 100Ω, 330Ω, 1kΩ, 2kΩ, & 5.1kΩ (as well as 10kΩ for the pulldowns). Likewise, I designed the pcb to fit the school resistors and not my own. That means that the spaces between the tht pads are actually too short, and I need to bend back one of the legs to get it to sit somewhat flat.



Then I soldered the box header. Now funny story. I forgot to mirror the led matrix panel output. That means that my box header needed to be soldered on the underside of the pcb! How fun! Anyway, I got it soldered on.



Time today: 1.75 hours  
**Time total: 29.5 hours**

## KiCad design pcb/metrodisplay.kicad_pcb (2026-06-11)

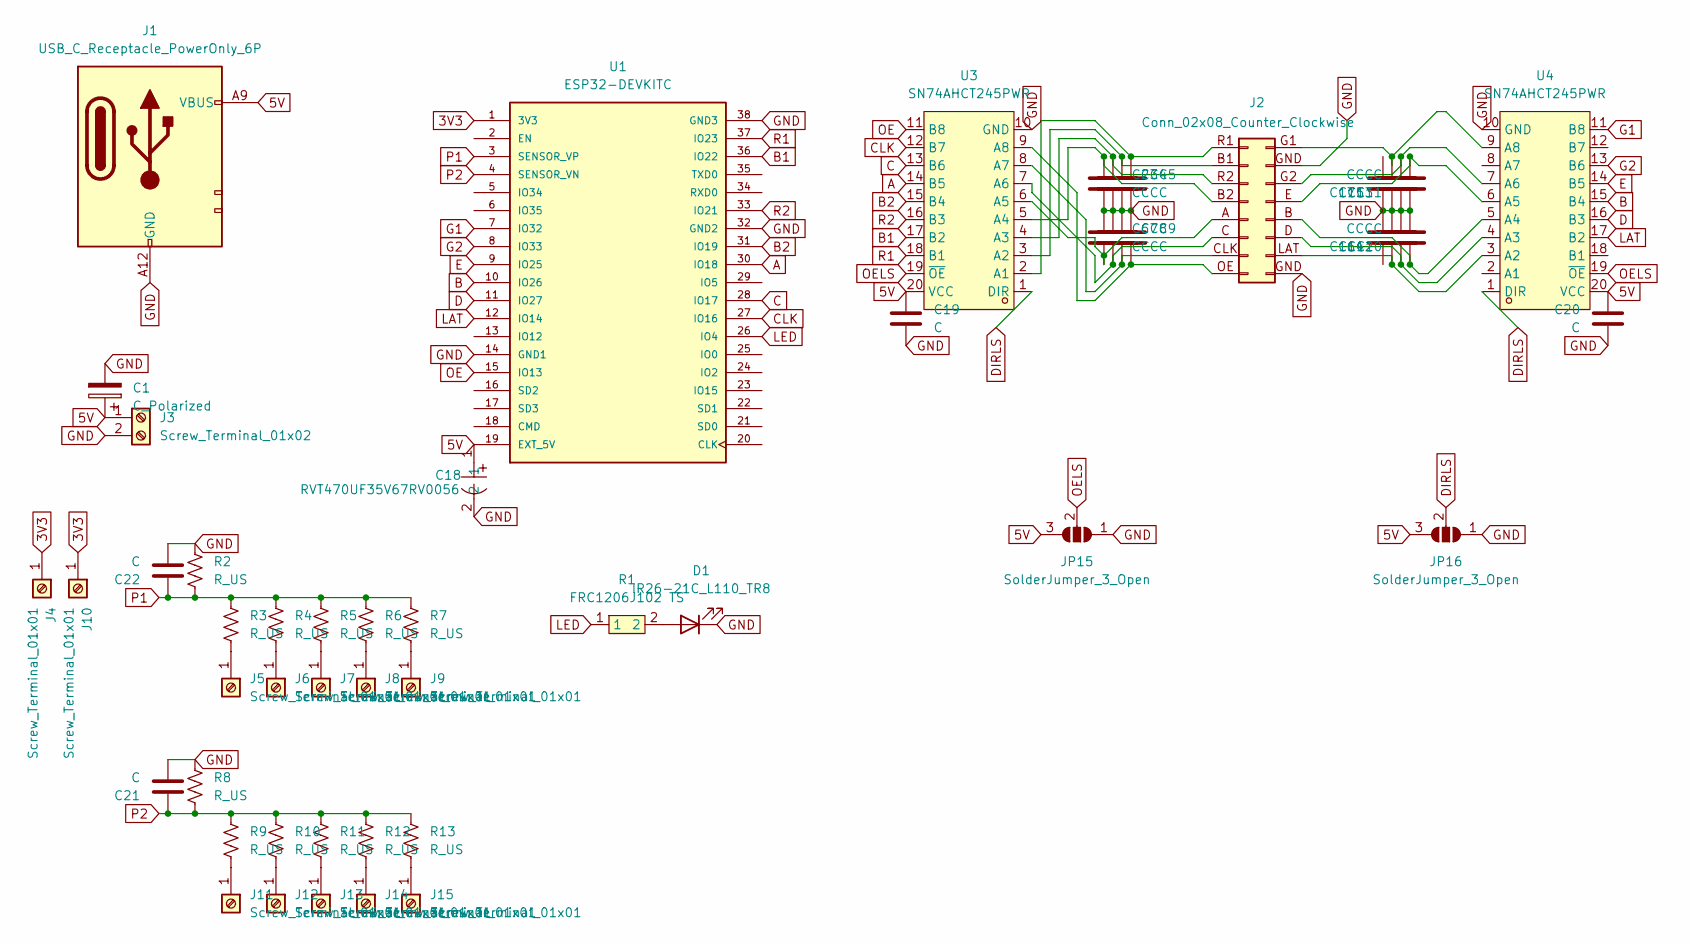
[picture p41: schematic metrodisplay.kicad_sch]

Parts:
C1: C_Polarized; CP_Radial_D16.0mm_P7.50mm
C2, C3, C4, C5, C6, C7, C8, C9, C10, C11, C12, C13, C14, C15, C16, C17, C19, C20, C21, C22: C; C1206
C18: RVT470UF35V67RV0056; CAP-SMD_BD10.0-L10.3-W10.3-LS11.0-FD; LCSC Part C2836436
D1: IR26-21C_L110_TR8; LED_1206_3216Metric
J1: USB_C_Receptacle_PowerOnly_6P; USB_C_PD_BOARD
J2: Conn_02x08_Counter_Clockwise; PinHeader_2x08_P2.54mm_Vertical_MD
J3: Screw_Terminal_01x02; TerminalBlock_Dinkle_DT-55-B01X-02_P10.00mm
J4, J5, J6, J7, J8, J9, J10, J11, J12, J13, J14, J15: Screw_Terminal_01x01; SolderWire-0.5sqmm_1x01_D0.9mm_OD2.1mm
JP15, JP16: SolderJumper_3_Open; SolderJumper-3_P2.0mm_Open_TrianglePad1.0x1.5mm
R1: FRC1206J102 TS; R1206; LCSC Part C2907440
R2, R3, R4, R5, R6, R7, R8, R9, R10, R11, R12, R13: R_US; R_Axial_DIN0204_L3.6mm_D1.6mm_P5.08mm_Horizontal
U1: ESP32-DEVKITC; MODULE_ESP32-DEVKITC; PARTREV N/A
U3, U4: SN74AHCT245PWR; TSSOP-20_L6.5-W4.4-P0.65-LS6.4-BL; MPN SN74AHCT245PWR; LCSC Part C10910

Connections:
3V3: J4.1 (Pin_1_1), J10.1 (Pin_1_1), U1.1 (3V3)
5V: C1.1, C18.1, C19.1, C20.1, J1.A9 (VBUS), J3.1, JP15.3 (B), JP16.3 (B), U1.19 (EXT_5V), U3.20 (VCC), U4.20 (VCC)
A: U1.30 (IO18), U3.14 (B5)
B: U1.10 (IO26), U4.15 (B4)
B1: U1.36 (IO22), U3.17 (B2)
B2: U1.31 (IO19), U3.15 (B4)
C: U1.28 (IO17), U3.13 (B6)
CLK: U1.27 (IO16), U3.12 (B7)
D: U1.11 (IO27), U4.16 (B3)
DIRLS: JP16.2 (C), U3.1 (DIR), U4.1 (DIR)
E: U1.9 (IO25), U4.14 (B5)
G1: U1.7 (IO32), U4.11 (B8)
G2: U1.8 (IO33), U4.13 (B6)
GND: C1.2, C2.2, C3.2, C4.2, C5.2, C6.1, C7.1, C8.1, C9.1, C10.2, C11.1, C12.2, C13.1, C14.2, C15.1, C16.2, C17.1, C18.2, C19.2, C20.2, C21.2, C22.2, D1.1 (K), J1.A12 (GND), J2.GND (Pin_9), J3.2, JP15.1 (A), JP16.1 (A), R2.1, R8.1, U1.14 (GND1), U1.32 (GND2), U1.38 (GND3), U3.10 (GND), U4.10 (GND); also elsewhere on the board
LAT: U1.12 (IO14), U4.17 (B2)
LED: R1.1, U1.26 (IO4)
unnamed: D1.2 (A), R1.2
unnamed: C5.1, J2.R1 (Pin_1), U3.2 (A1)
unnamed: C4.1, J2.B1 (Pin_2), U3.3 (A2)
unnamed: C3.1, J2.R2 (Pin_3), U3.4 (A3)
unnamed: C2.1, J2.B2 (Pin_4), U3.5 (A4)
unnamed: C6.2, J2.A (Pin_5), U3.6 (A5)
unnamed: C7.2, J2.C (Pin_6), U3.7 (A6)
unnamed: C8.2, J2.CLK (Pin_7), U3.8 (A7)
unnamed: C9.2, J2.OE (Pin_8), U3.9 (A8)
unnamed: C14.1, J2.LAT (Pin_10), U4.3 (A2)
unnamed: C12.1, J2.D (Pin_11), U4.4 (A3)
unnamed: C10.1, J2.B (Pin_12), U4.5 (A4)
unnamed: C11.2, J2.E (Pin_13), U4.6 (A5)
unnamed: C13.2, J2.G2 (Pin_14), U4.7 (A6)
unnamed: C15.2, J2.G1 (Pin_16), U4.9 (A8)
unnamed 31: J5.1, R3.2; also elsewhere on the board
unnamed: J6.1 (Pin_1_1), R4.2
unnamed: J7.1 (Pin_1_1), R5.2
unnamed: J8.1 (Pin_1_1), R6.2
unnamed: J9.1 (Pin_1_1), R7.2
unnamed: J11.1 (Pin_1_1), R9.2
unnamed: J12.1 (Pin_1_1), R10.2
unnamed: J13.1 (Pin_1_1), R11.2
unnamed: J14.1 (Pin_1_1), R12.2
unnamed: J15.1 (Pin_1_1), R13.2
OE: U1.15 (IO13), U3.11 (B8)
OELS: JP15.2 (C), U3.19 (~OE), U4.19 (~OE)
P1: C22.1, R2.2, R3.1, R4.1, R5.1, R6.1, R7.1, U1.3 (SENSOR_VP); also elsewhere on the board
P2: C21.1, R8.2, R9.1, R10.1, R11.1, R12.1, R13.1, U1.4 (SENSOR_VN)
R1: U1.37 (IO23), U3.18 (B1)
R2: U1.33 (IO21), U3.16 (B3)

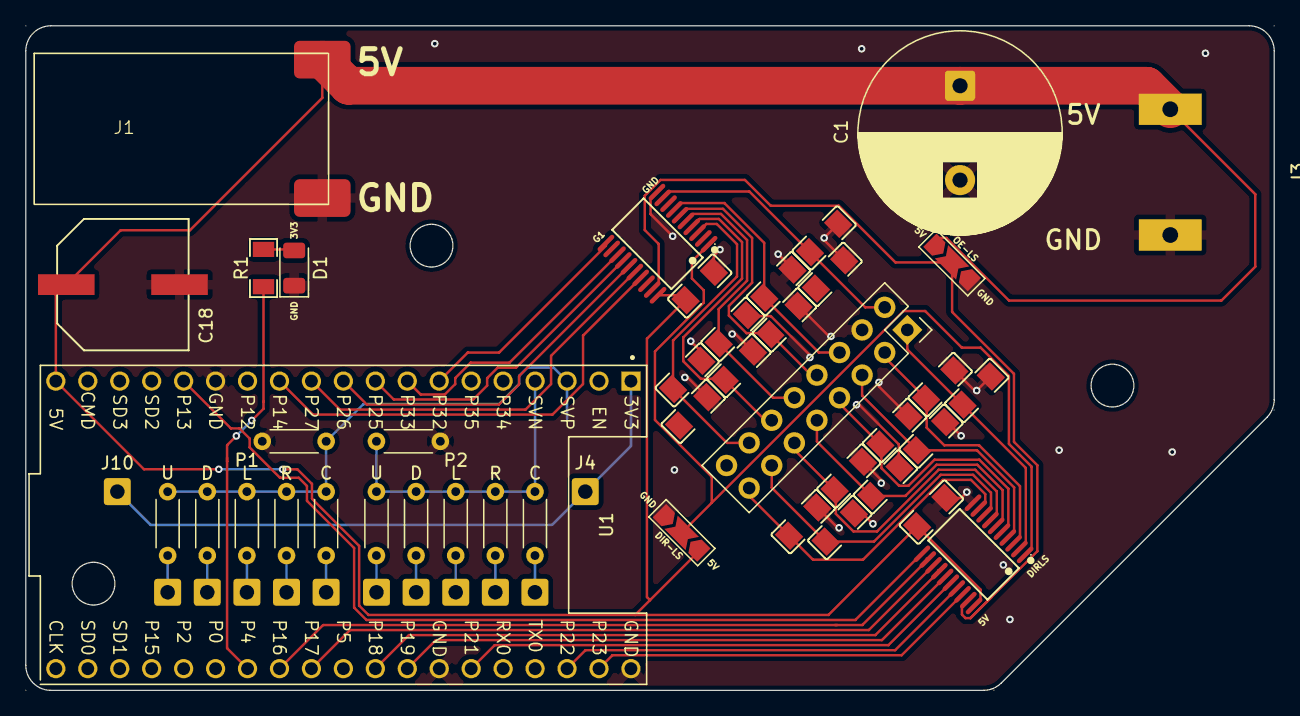
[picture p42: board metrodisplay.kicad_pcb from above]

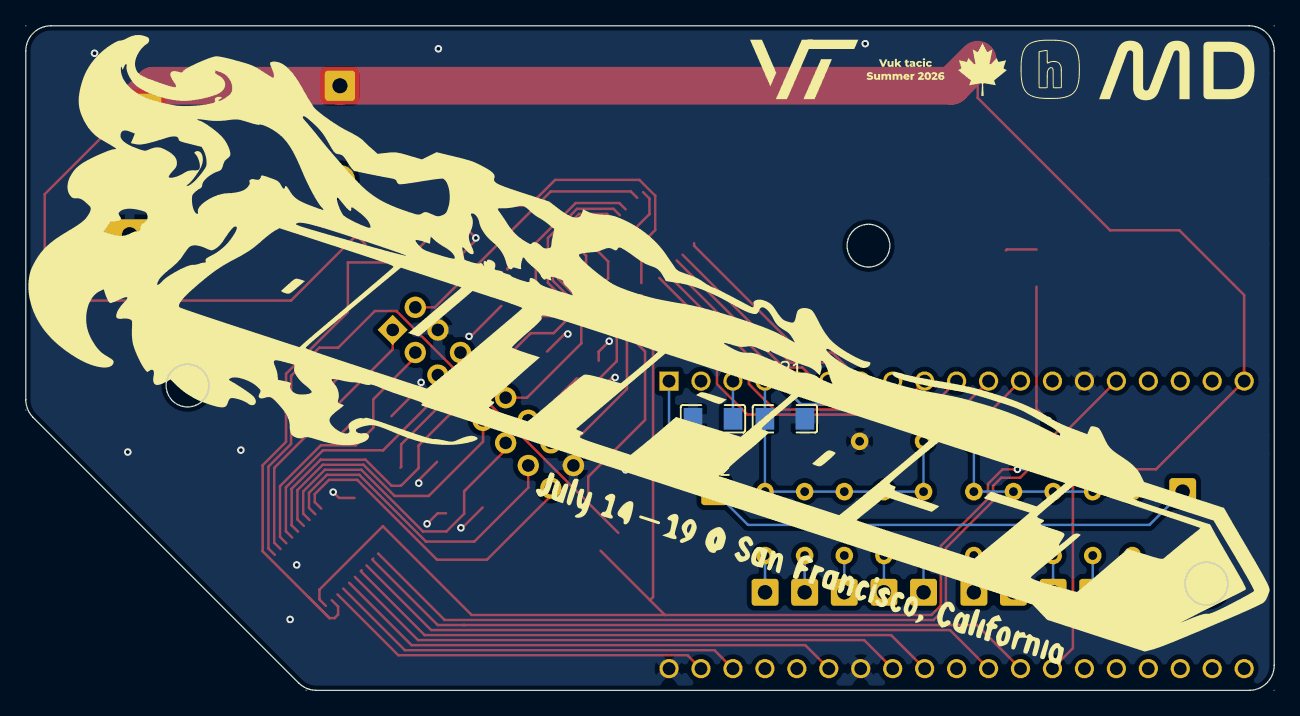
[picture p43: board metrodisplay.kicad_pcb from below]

Board: 2 copper layers, 99.2 x 52.8 mm, 56 parts (2 on the bottom side), 47 nets.

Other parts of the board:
P1: R_US; R_Axial_DIN0204_L3.6mm_D1.6mm_P5.08mm_Horizontal
U: Screw_Terminal_01x01; SolderWire-0.5sqmm_1x01_D0.9mm_OD2.1mm

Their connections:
GND: P1.1; also elsewhere on the board
unnamed 31: U.1 (Pin_1_1); also elsewhere on the board
P1: P1.2; also elsewhere on the board

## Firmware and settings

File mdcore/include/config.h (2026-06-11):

#pragma once
#include <Arduino.h>

constexpr int BUTTON_UP_THRESHOLD = 400;
constexpr int BUTTON_DOWN_THRESHOLD = 1200;
constexpr int BUTTON_LEFT_THRESHOLD = 2000;
constexpr int BUTTON_RIGHT_THRESHOLD = 2800;
constexpr int BUTTON_CENTER_THRESHOLD = 3600;

#define P1_PIN 34
#define P2_PIN 39

constexpr int R1_PIN = 25;
constexpr int G1_PIN = 26;
constexpr int B1_PIN = 27;
constexpr int R2_PIN = 14;
constexpr int G2_PIN = 12;
constexpr int B2_PIN = 13;
constexpr int A_PIN  = 23;
constexpr int B_PIN  = 19;
constexpr int C_PIN  = 5;
constexpr int D_PIN  = 17;
constexpr int E_PIN  = -1;
constexpr int LAT_PIN = 4;
constexpr int OE_PIN  = 15;
constexpr int CLK_PIN = 16;

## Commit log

2026-06-06 Add PCB
    [metrodisplay.kicad_pcb, metrodisplay.kicad_sch]
2026-06-06 PCB Routing test
    [metrodisplay.kicad_pcb, metrodisplay.kicad_sch]
2026-06-07 PCB routing done
    [metrodisplay.kicad_pcb, metrodisplay.kicad_sch]
2026-06-08 PCB done
    [DS1013-16S (IDC-16MS CONNFLY).stp, metrodisplay.kicad_pcb, pcb.step]
2026-06-08 Track ./assets/ with git LFS
2026-06-10 Enclosure cadded
    [metrodisplay.kicad_pcb]
2026-06-11 Pong game!
    [metrodisplay.kicad_pcb, metrodisplay.kicad_sch, pcb.step]
2026-06-11 Add updated fusion files
    [Controller.f3z, Controller.step]
2026-06-11 Update sheets
    [acpower.kicad_sch, metrodisplay.kicad_sch]
2026-06-11 BOM & journal
    [bom.csv]
2026-06-11 Fix bom.csv
    [bom.csv]
2026-06-11 Fix bom.csv pt2
    [bom.csv]
2026-06-11 Fix bom.csv pt3
    [bom.csv]
2026-06-12 Add PCB to bom.csv
    [bom.csv]
